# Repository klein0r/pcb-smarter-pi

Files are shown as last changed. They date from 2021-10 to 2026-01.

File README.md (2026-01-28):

# Smarter Pi PCB

[Gerber-Files](https://github.com/klein0r/pcb-smarter-pi/releases)

## Preview

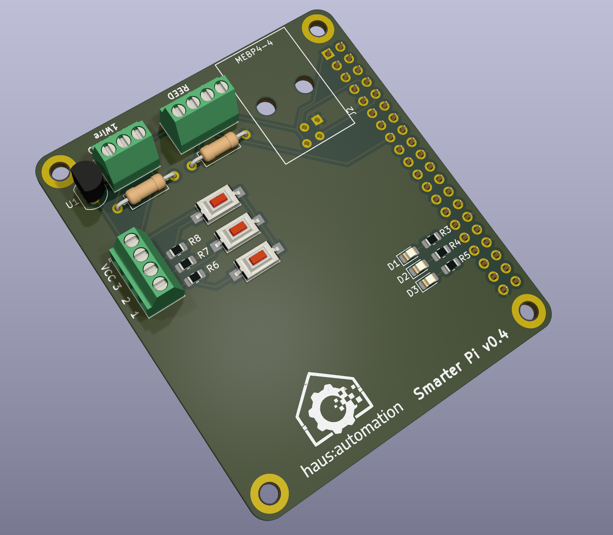
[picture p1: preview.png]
PCB Preview


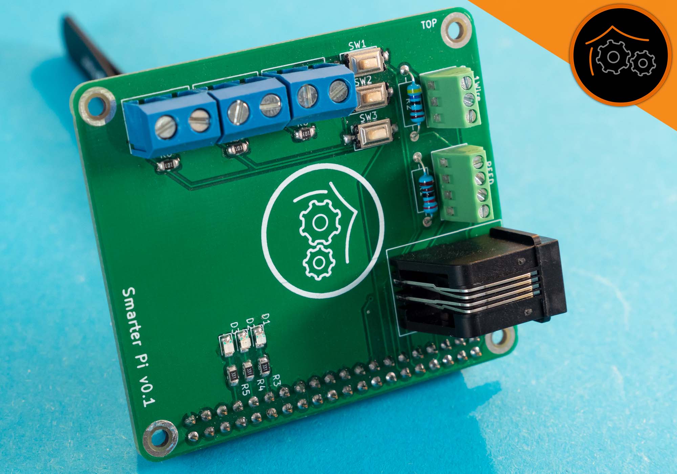
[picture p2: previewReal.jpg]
PCB Photo


## Features

- 1-Wire Interface (GPIO4)
- Reed sensor Support (GPIO22)
- RJ10 for serial interface (RX / TX)
- 3x SMD LED
- 3x Buttons (SMD or external terminal block)

## Parts

- J1: MPE 094-2-040 (20x2 connector)
- J2: MEBP4-4
- J3, J5: PHC 1725672 - MPT 0,5/ 4-2,54
- J4: PHC 1725669 - MPT 0,5/ 3-2,54
- R1: Resistor DIN0207 2.2k
- R2: Resistor DIN0207 4.7k
- R3, R4, R5: Resistor SMD 0805 330
- R6, R7, R8: Resistor SMD 0805 10k
- D1, D2, D3: LED SMD 0805
- SW1, SW2, SW3: Push Button (3.81)
- U1: DS18B20

## License

The MIT License (MIT)

Copyright (c) 2026 Matthias Kleine <info@haus-automatisierung.com>

Permission is hereby granted, free of charge, to any person obtaining a copy
of this software and associated documentation files (the "Software"), to deal
in the Software without restriction, including without limitation the rights
to use, copy, modify, merge, publish, distribute, sublicense, and/or sell
copies of the Software, and to permit persons to whom the Software is
furnished to do so, subject to the following conditions:

The above copyright notice and this permission notice shall be included in
all copies or substantial portions of the Software.

THE SOFTWARE IS PROVIDED "AS IS", WITHOUT WARRANTY OF ANY KIND, EXPRESS OR
IMPLIED, INCLUDING BUT NOT LIMITED TO THE WARRANTIES OF MERCHANTABILITY,
FITNESS FOR A PARTICULAR PURPOSE AND NONINFRINGEMENT. IN NO EVENT SHALL THE
AUTHORS OR COPYRIGHT HOLDERS BE LIABLE FOR ANY CLAIM, DAMAGES OR OTHER
LIABILITY, WHETHER IN AN ACTION OF CONTRACT, TORT OR OTHERWISE, ARISING FROM,
OUT OF OR IN CONNECTION WITH THE SOFTWARE OR THE USE OR OTHER DEALINGS IN
THE SOFTWARE.

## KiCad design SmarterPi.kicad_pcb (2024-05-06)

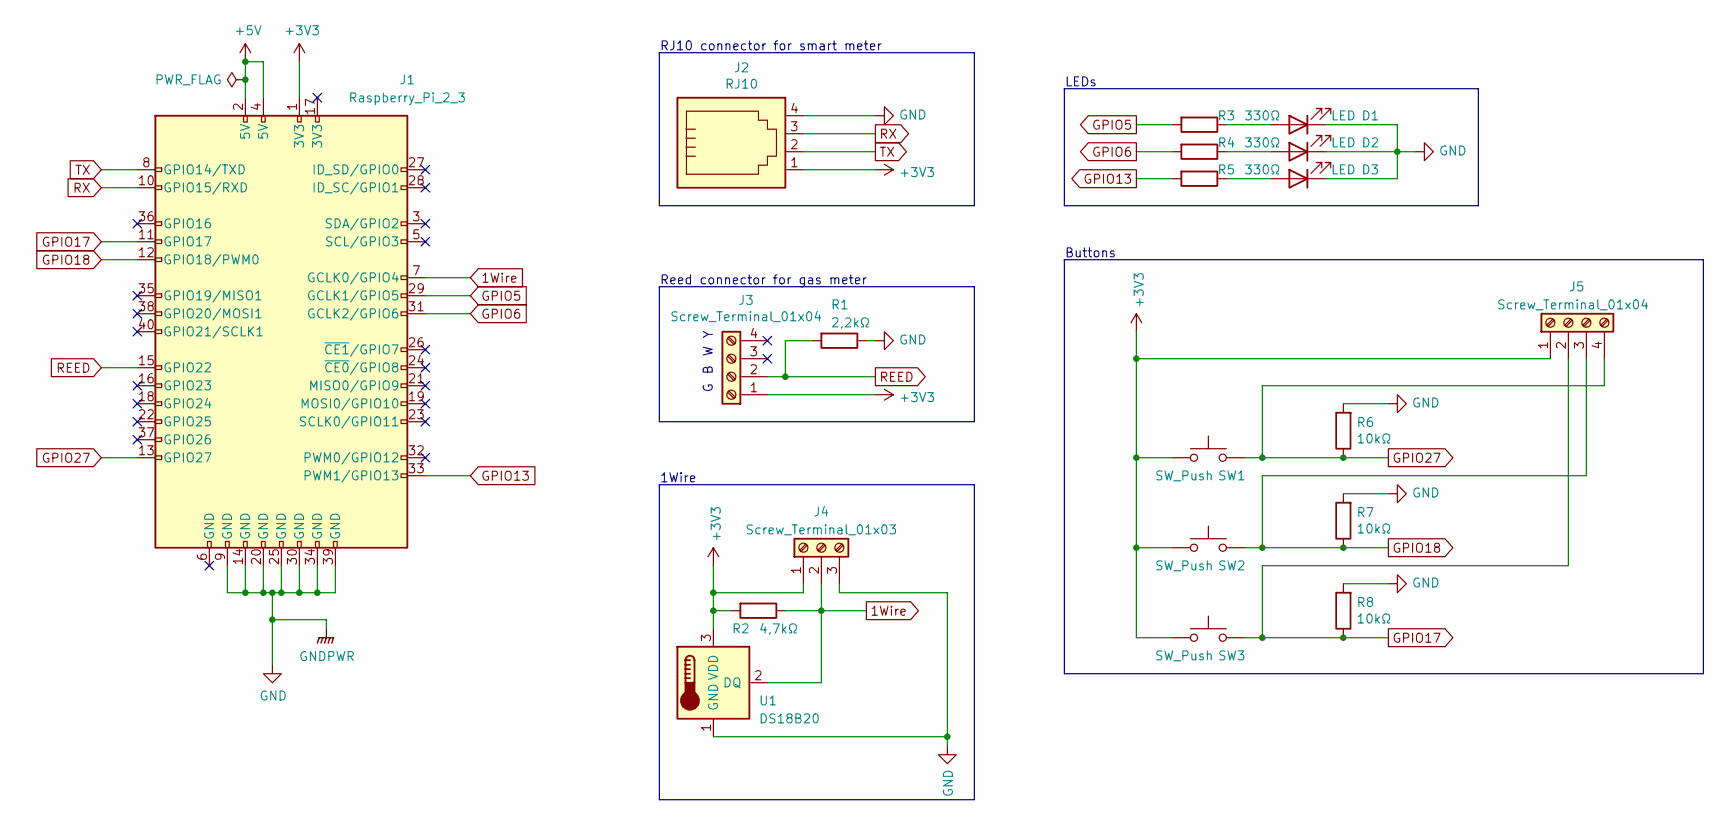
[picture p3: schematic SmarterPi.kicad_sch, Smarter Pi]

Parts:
D1, D2, D3: LED; LED_0805_2012Metric_Pad1.15x1.40mm_HandSolder
J1: Raspberry_Pi_2_3; PinSocket_2x20_P2.54mm_Vertical
J2: RJ10; MEBP_44S
J3, J5: Screw_Terminal_01x04; TerminalBlock_Phoenix_MPT-0,5-4-2.54_1x04_P2.54mm_Horizontal
J4: Screw_Terminal_01x03; TerminalBlock_Phoenix_MPT-0,5-3-2.54_1x03_P2.54mm_Horizontal
R1: 2,2kΩ; R_Axial_DIN0207_L6.3mm_D2.5mm_P10.16mm_Horizontal
R2: 4,7kΩ; R_Axial_DIN0207_L6.3mm_D2.5mm_P10.16mm_Horizontal
R3, R4, R5: 330Ω; R_0805_2012Metric_Pad1.20x1.40mm_HandSolder
R6, R7, R8: 10kΩ; R_0805_2012Metric_Pad1.20x1.40mm_HandSolder
SW1, SW2, SW3: SW_Push; SW_SPST_CK_RS282G05A3
U1: DS18B20; TO-92_Inline

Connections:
1Wire: J1.7 (GCLK0/GPIO4), J4.2, R2.1, U1.2 (DQ)
+3V3: J1.1 (3V3), J2.1, J3.1, J4.1, J5.1, R2.2, SW1.1, SW2.1, SW3.1, U1.3 (VDD)
+5V: J1.2 (5V), J1.4 (5V)
GND: D1.1 (K), D2.1 (K), D3.1 (K), J1.9 (GND), J1.14 (GND), J1.20 (GND), J1.25 (GND), J1.30 (GND), J1.34 (GND), J1.39 (GND), J2.4, J4.3, R1.1, R6.2, R7.2, R8.2, U1.1 (GND)
GPIO5: J1.29 (GCLK1/GPIO5), R3.2
GPIO6: J1.31 (GCLK2/GPIO6), R4.2
GPIO13: J1.33 (PWM1/GPIO13), R5.2
GPIO17: J1.11 (GPIO17), J5.2, R8.1, SW3.2
GPIO18: J1.12 (GPIO18/PWM0), J5.3, R7.1, SW2.2
GPIO27: J1.13 (GPIO27), J5.4, R6.1, SW1.2
unnamed: D1.2 (A), R3.1
unnamed: D2.2 (A), R4.1
unnamed: D3.2 (A), R5.1
REED: J1.15 (GPIO22), J3.2, R1.2
RX: J1.10 (GPIO15/RXD), J2.3
TX: J1.8 (GPIO14/TXD), J2.2

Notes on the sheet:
RJ10 connector for smart meter
1Wire
Reed connector for gas meter
Buttons
LEDs

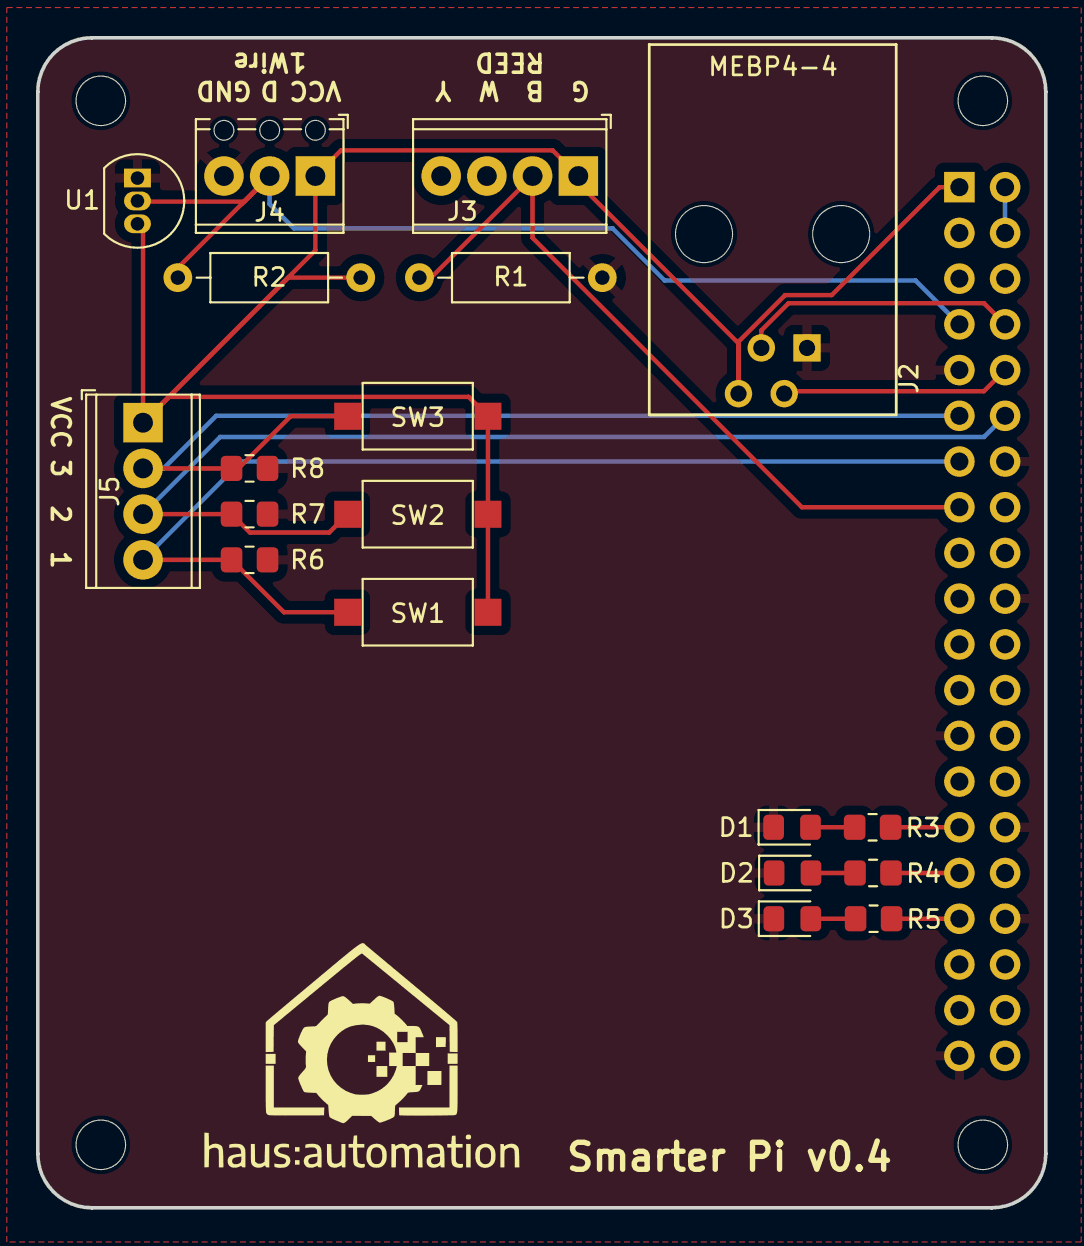
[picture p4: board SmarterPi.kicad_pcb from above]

Board: 2 copper layers, 56.0 x 65.0 mm, 24 parts (1 on the bottom side), 16 nets.

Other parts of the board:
H1, H2, H5, H6: MountingHole; MountingHole_2.75mm_NoPad

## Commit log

2021-02-02 RJ10 Adapter for serial
    [SmarterPi.kicad_pcb, SmarterPi.sch]
2021-02-18 Readme, License, Preview
    [SmarterPi.kicad_pcb, SmarterPi.sch]
2021-02-18 Added LEDs
    [SmarterPi.kicad_pcb, SmarterPi.sch]
2021-02-19 Added 3 push buttons
    [SmarterPi.kicad_pcb, SmarterPi.sch]
2021-02-19 Minor fixes
    [SmarterPi.kicad_pcb, SmarterPi.sch]
2021-10-21 Smaller terminal block for buttons
    [SmarterPi.kicad_pcb, SmarterPi.sch]
2021-10-21 Added DS18B20
    [SmarterPi.kicad_pcb, SmarterPi.sch]
2022-01-30 Updated to KiCad 6
    [SmarterPi.kicad_pcb, SmarterPi.kicad_sch, SmarterPi.sch]
